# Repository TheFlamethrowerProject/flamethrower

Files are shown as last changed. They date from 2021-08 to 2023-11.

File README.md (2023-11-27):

# DIY Flamethrower - This is not a toy

<sup>This repository is still under construction. Links may be innactive and not all files have been uploaded.</sup>
<!-- ![](Media/Logo.jpg)   -->

**The DIY Flamethrower**  - Personal, handheld, butane fueled, 3D printed flamethrower!

Great for cooking, cleaning, and tons of recreational activities! 



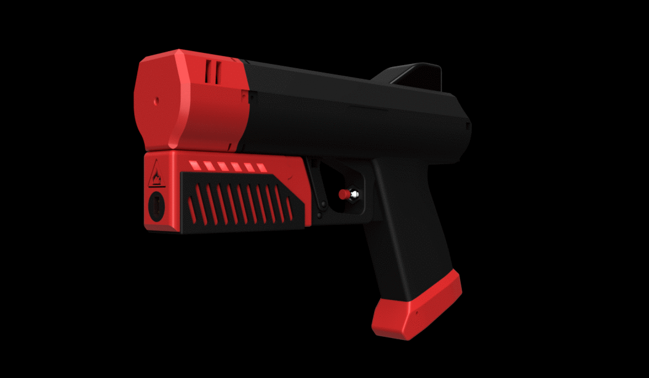
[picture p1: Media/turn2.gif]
  

## How it works
The 3D Printed shell houses a full 135ml can of butane which rests in the printed nozzle. The can is actuated by an N20 geared motor and the butane is ignited via a plasma arc in the path of the spray. All of the electronics are code-free and clearly layed out in [Wiring]()

This version has no metal fastners. Just 3d printed links and clever ziptie usage.

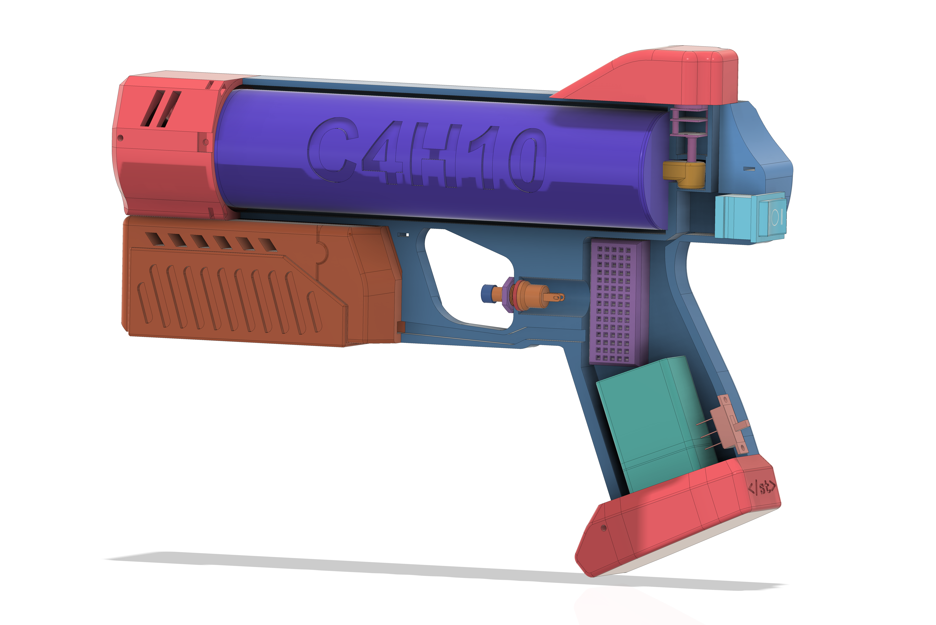
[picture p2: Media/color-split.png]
 

<!-- *[YouTube link]()* -->

## The Build
Detailed assembly instruction are given in the [Wiki](https://github.com/TheFlamethrowerProject/flamethrower/wiki). Please follow each step to complete the build and start THROWING FLAMES! Safely of course :)

[0. Warning](https://github.com/TheFlamethrowerProject/flamethrower/wiki/0.-Warning)

[1. Hardware Setup](https://github.com/TheFlamethrowerProject/flamethrower/wiki/1.-Hardware-Setup)

[2. Materials needed](https://github.com/TheFlamethrowerProject/flamethrower/wiki/2.-Materials)

[3. Safety and Usage Guide](https://github.com/TheFlamethrowerProject/flamethrower/wiki/3.-Safety-and-Usage)

[4. Customize and Share](https://github.com/TheFlamethrowerProject/flamethrower/wiki/4.-Customize-and-Share)

## Images
> I'll add some soon
## FAQ
> Won't the plastic Melt?
Nope. The butane is ignited far away fom the plastic. The chassis will remain at air temperature and will get colder as the butane can empties. The flame is a significant distance away from the device.
---

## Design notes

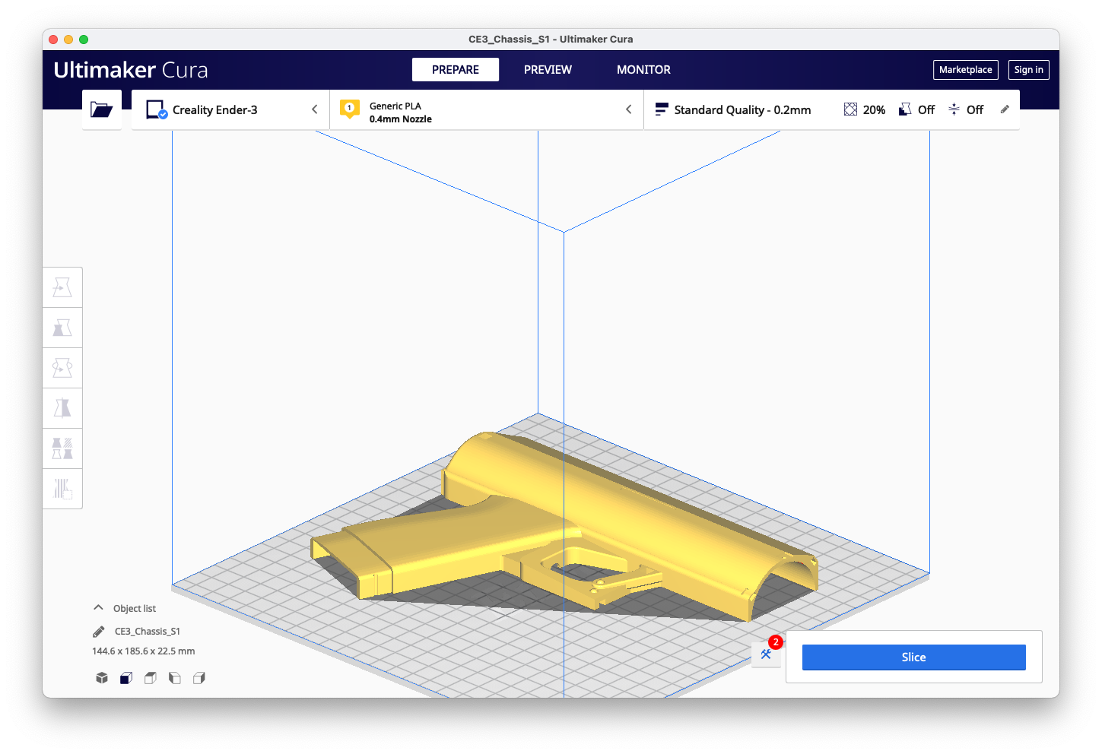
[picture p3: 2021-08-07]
Media/PrintOrientation/Chassis_S1.png

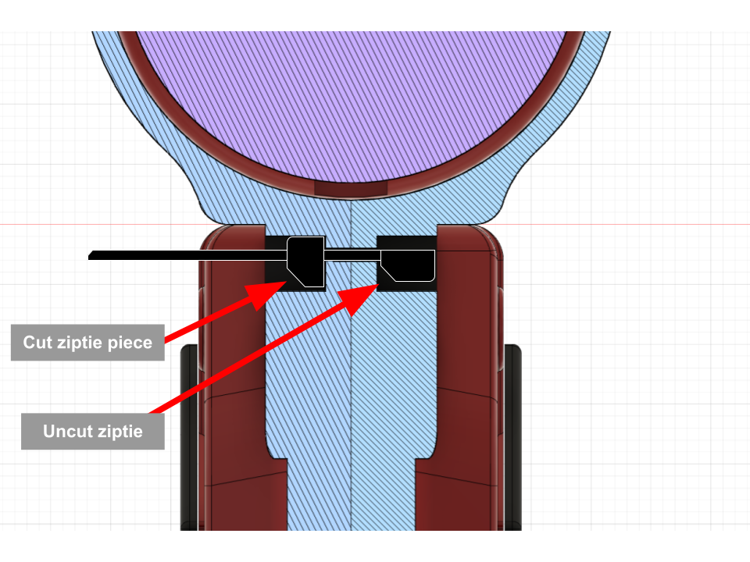
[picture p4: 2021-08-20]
Media/ziptie diagram.png

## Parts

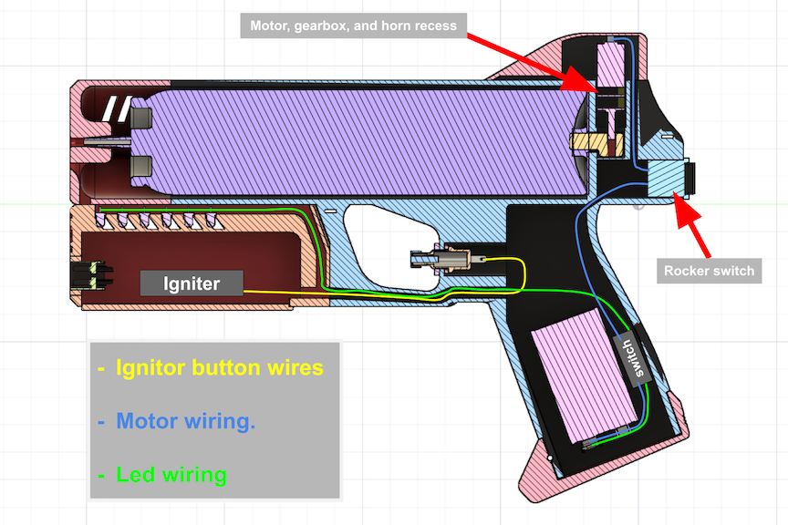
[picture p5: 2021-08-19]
Media/component_layout.png

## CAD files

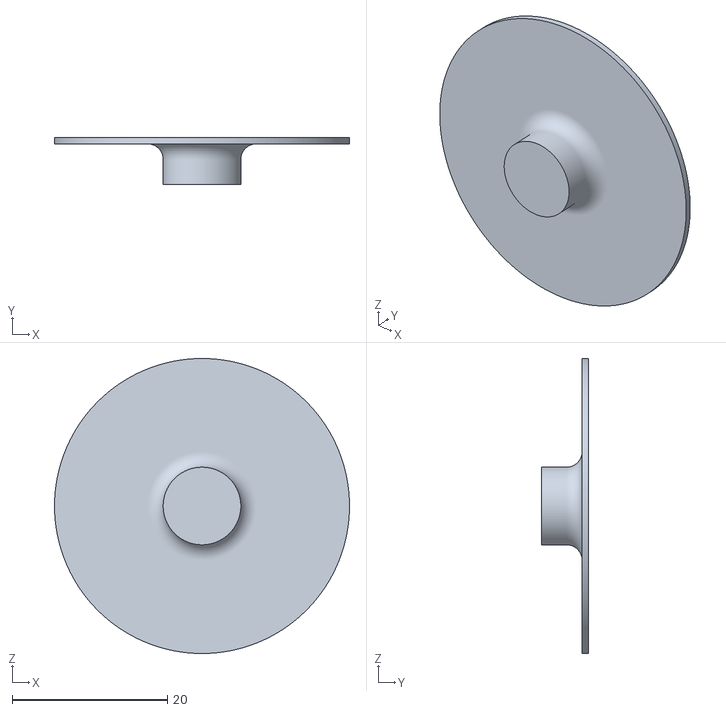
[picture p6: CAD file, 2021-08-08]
Hardware/STL/Disk.stl
38.0 x 6.00 x 38.0

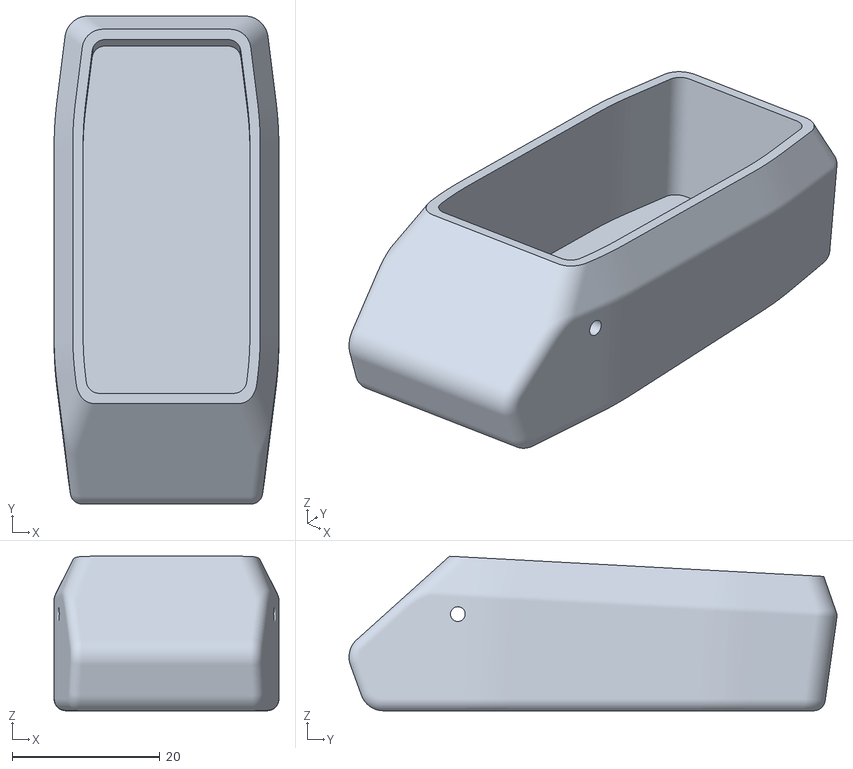
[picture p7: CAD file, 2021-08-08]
Hardware/STL/Bottom.stl
30.5 x 66.1 x 21.0

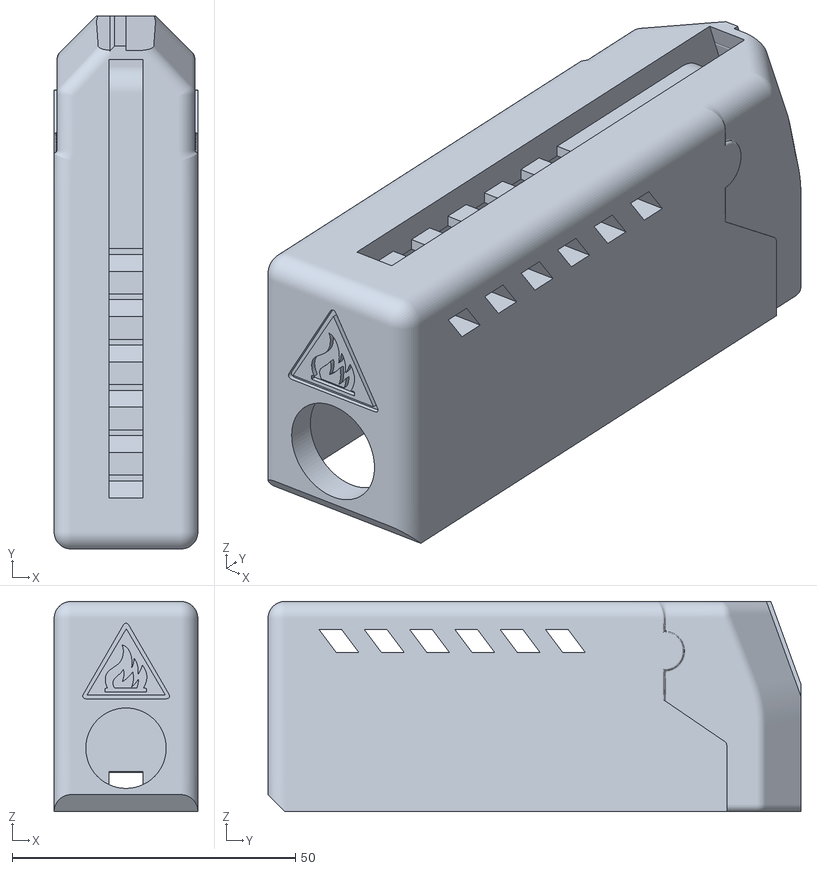
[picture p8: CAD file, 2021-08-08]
Hardware/STL/Box.stl
25.4 x 94.2 x 37.1

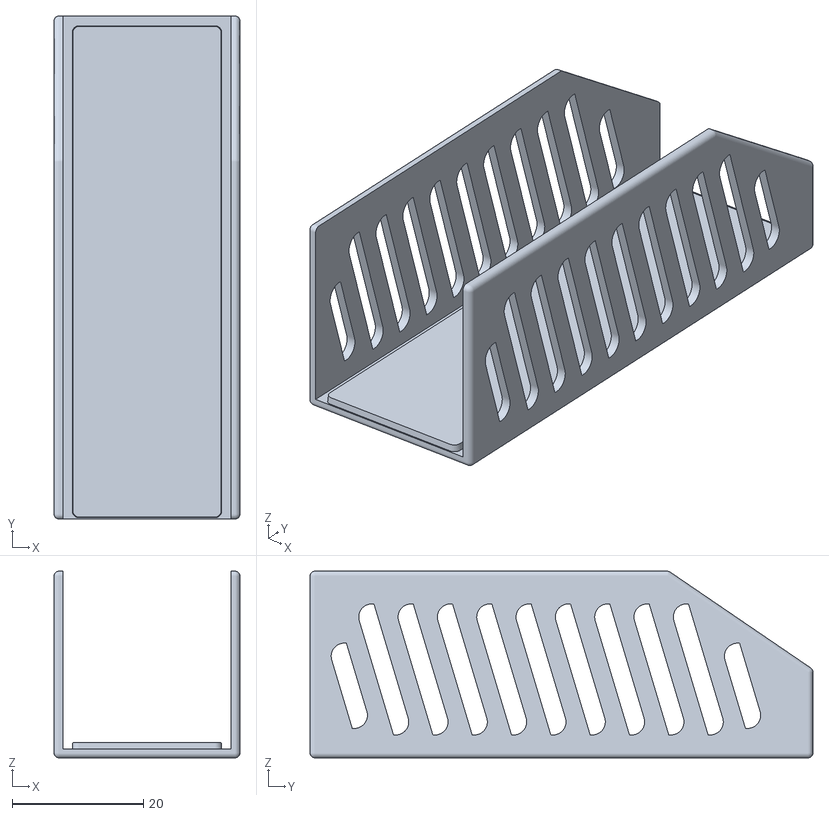
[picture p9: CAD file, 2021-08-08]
Hardware/STL/Cage.stl
28.4 x 76.7 x 28.5

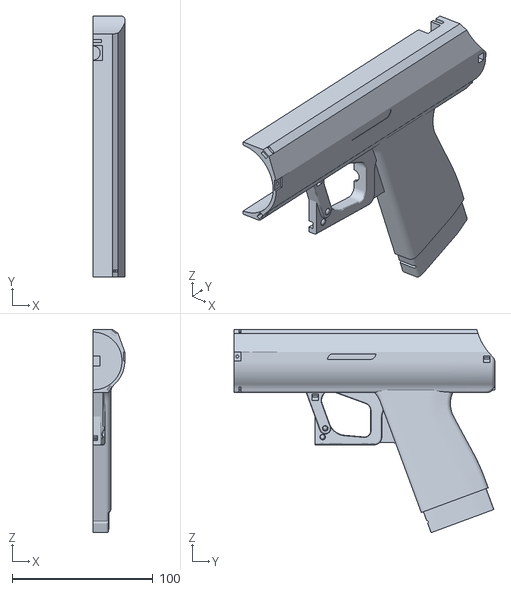
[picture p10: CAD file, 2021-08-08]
Hardware/STL/Chassis S2.stl
22.5 x 185.6 x 144.6

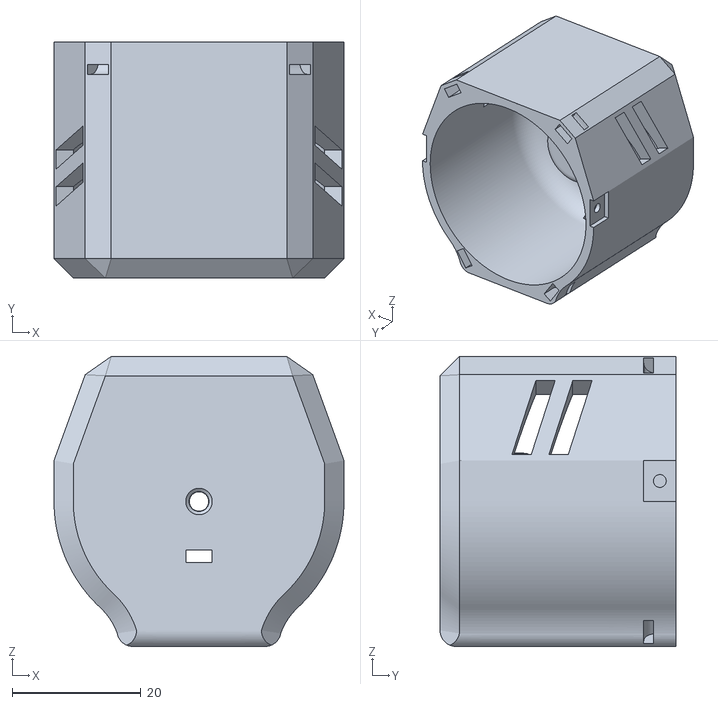
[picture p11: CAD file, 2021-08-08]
Hardware/STL/Nozzle-ignite.stl
45.0 x 36.6 x 45.0

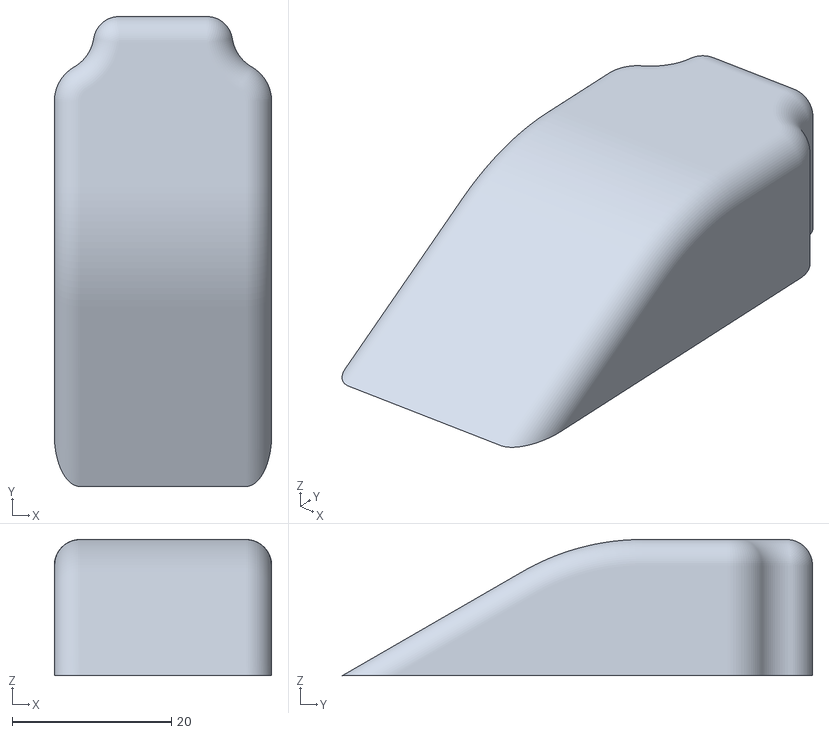
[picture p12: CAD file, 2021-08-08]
Hardware/STL/Top Cover.stl
27.3 x 59.0 x 17.1

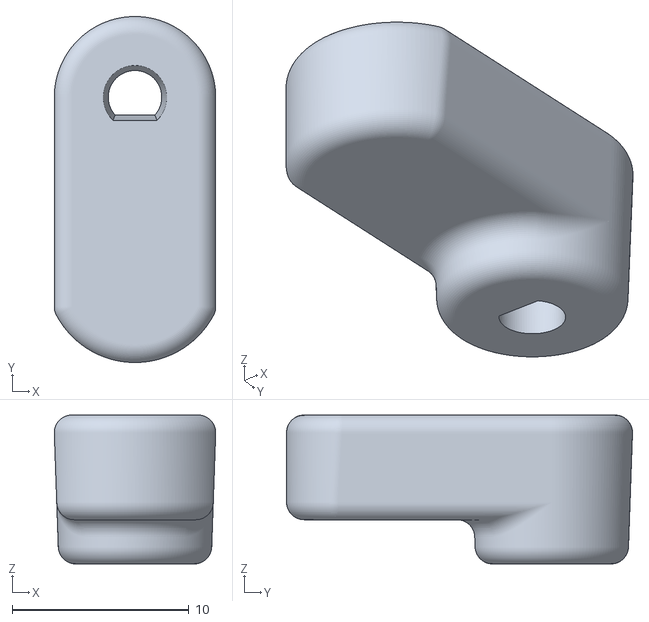
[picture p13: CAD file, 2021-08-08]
Hardware/STL/N20 Horn.stl
9.13 x 19.6 x 8.42

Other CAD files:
Hardware/STL/Chassis S1.stl

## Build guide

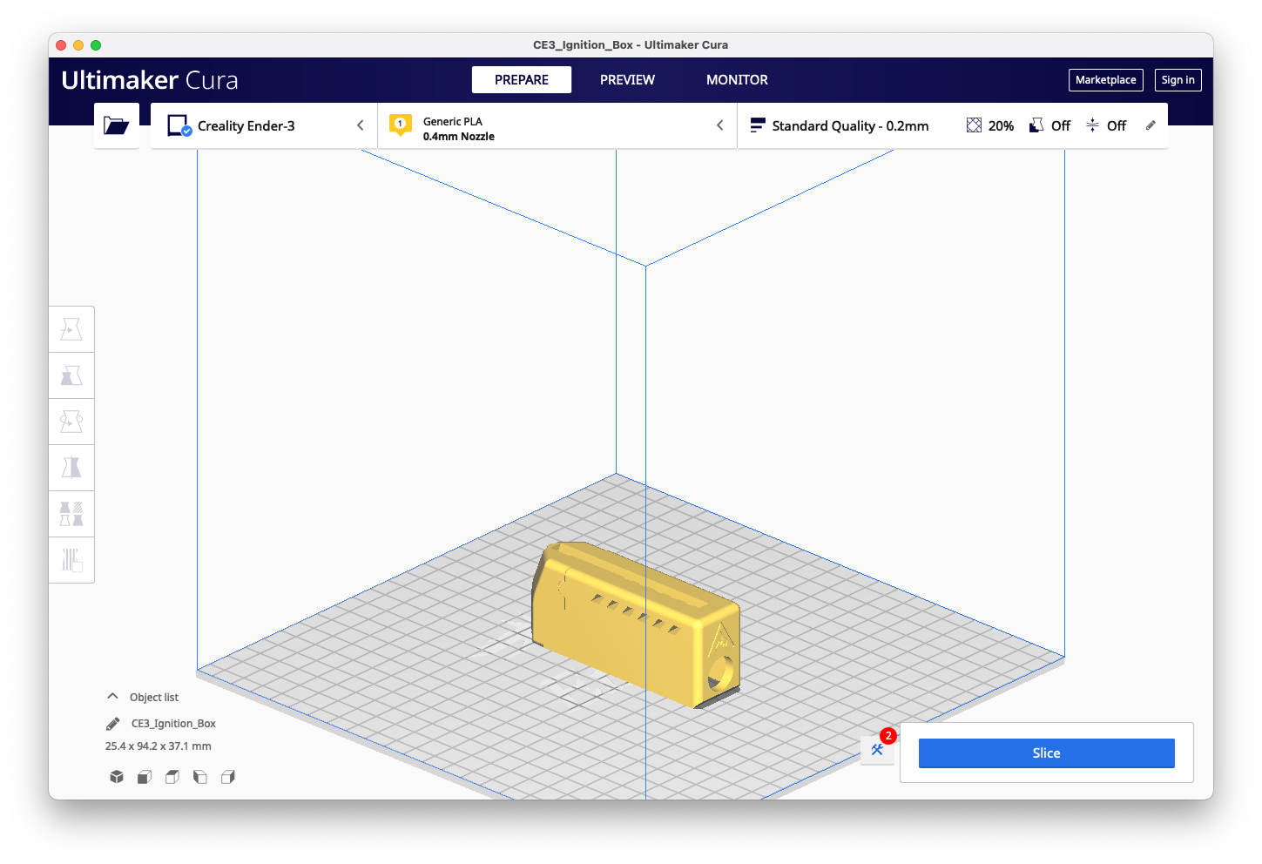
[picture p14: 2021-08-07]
Media/PrintOrientation/box.png

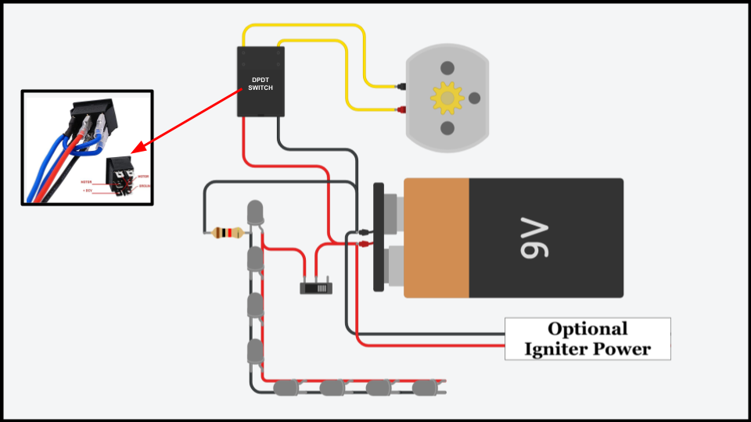
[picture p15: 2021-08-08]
Wiring/Wiring1.png

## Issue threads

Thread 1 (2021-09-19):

Rocker swifch

jcpoling, 2021-09-19:
Hello,

I ordered the material list but the rocker switch is too big for the build. Can you recommend a suitable replacement? I tried looking on Amazon but can’t find anything.

I printed the first chassis and it turned out great.

Also looks like there is a wiring component that connects the lights but I’m not sure what it’s called or what to buy. Can you share?

Thanks!

SamsonTaxon, 2021-09-19:
I'm so glad to hear that you're working on this project. I got that rocker switch from [this motor controller](https://www.amazon.com/gp/product/B07BLWXXQC/ref=ppx_yo_dt_b_search_asin_title?ie=UTF8&psc=1) and used the board for a separate project. I can't find the source of the rocker switch alone on amazon but you can purchase the whole assembly here and just use the switch as I did. As for the lights I'm not sure what assembly you're referring to. I soldered the leads of the leds directly to each other and then wires to extend them to the power.

jcpoling, 2021-09-19:
Perfect thank you! This is the piece I’m referring to.
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

SamsonTaxon, 2021-09-20:
That is a resistor. It drops down the voltage from the battery so the LEDs don't burn out. A pack of them comes with the linked led pack but you can use a resistor calculator to figure out what resistance you need if you sourced the LEDs on your own. You can also take the risk of connecting all the LEDs directly to the battery as I did. This won't work with one LED but if enough are strung together you might be okay. A resistor is likely the safest option.

helibot, 2021-09-27:
Thanks for sharing this great project. I have started printing and purchasing parts.
I notice that the motor you specified is rated 3V , yet you are connecting this to 9V battery? Depending on the motor , overdriving it may work ok , or it may not.  At least I expect it would run faster!!  Did you measure what speed the motor was turning at with the 9V battery?  (Was it still the rated 5revs per minute? or faster?)
What power was needed for the igniter? (if it was a button battery then likely 3V?)
So I am wondering if I should use 2 x 1.5V AA batteries to give 3V instead to power both the battery and the igniter?

Also a final question.....do you just need to use the igniter to start the gas burning (and then release it) or do you need to keep the igniter pressed to keep the flames lit?

SamsonTaxon, 2021-09-27:
I'm glad to hear you're working on the project. I haven't measured the speed but at 9 volts it definitely moves faster than 5RPM which is preferable. Torque is the most important metric followed by speed and 9volts provides optimal performance. In my build the ignitor is powered by the included rechargeable battery but you could add a regulator and drop down the 9volts to 3.7 to power the ignitor board.

The ignitor does not need to remain on the entire time and it will not remain on for long periods of time even if you hol d down the button. I activate the ignitor once and then reactivate if the flame stops.

Please update the community on your progress by tweeting pictures @SamsonTaxon. Let me know if you have any other questions.

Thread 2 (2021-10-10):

Size of gas canister

helibot, 2021-10-10:
Hi again,
  I have sourced some [gas canisters locally](https://www.bunnings.com.au/tradeflame-60g-push-on-butane-power-gas-cartridge_p5910255), they are shorter than yours. But thought they would be the same diameter. But after printing both halves I found the canister would be very tight and would not slide easily.  I did have a little warping of my print though so not sure if the canisters are too big or the warping is the problem.

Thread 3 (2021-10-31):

How do I wire the DPDT switch?

nmkoza, 2021-10-31:
I am confused on what I do with the dpdt switch. right now in the project I have the battery power cable going to the normal switch then another set of wires going to the dpdt switch. What do I do with these 2 wires?

nmkoza, 2021-10-31:
I do see a mini diagram next to the wiring diagram but I cannot read that at all.

nmkoza, 2021-11-02:
Update: I figured it out. On the back of the switch there will be 4 wires coming off of the switch. 2 of them will be connected to the left and right middle points. The other 2 will be one red and one black one coming off the left and the right. The middle 2 go to the motor and the red and black ones go right to the battery wire.

Closed 2021-11-02.

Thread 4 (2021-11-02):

Snake Arc Lighter wiring.

nmkoza, 2021-11-02:
Hey, I am at the part where I wire the lighters board to the button. From my understanding, in the image you posted of the board, the yellow wires that come off the same solder point as the copper wires go to the button. Is that correct? Also on the other half the board you have 3 other wires coming off of it (2 red and 1 black). On my board those 2 red wires are blue and they are connected to a micousb. Is that what yours are or did you solder those to something else? And the black wire is where my battery is, What does that black wire go to? This is the picture I am talking about: [https://imgur.com/undefined](url).

nmkoza, 2021-11-06:
I found out that soldering the yellow wires to the left side of the button on the board on the top and bottom pad works for the button. I might have a different bored than the one on the github but that is what worked for me.

Closed 2021-11-06.

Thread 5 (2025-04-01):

rocker switch wiring

burntsushi421345, 2025-04-01:
hello, I'm having a bit of trouble figuring out how to wire the rocker switch to the motor and power, specifically which wire goes to witch pin and witch way the motor should turn.

this is not a issue, as i think most people were able to figure this out, but not me.

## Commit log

2021-08-07 print orientation
2021-08-08 stl files
    [Bottom.stl, Box.stl, Cage.stl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]
